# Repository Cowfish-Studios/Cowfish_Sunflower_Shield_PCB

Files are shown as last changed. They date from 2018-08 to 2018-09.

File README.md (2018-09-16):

Cowfish Studios Sunflower Shield
==============

Cowfish Studios Sunflower Shield

[*Cowfish Studios Sunflower Shield*](http://kck.st/2NdfVJ6)

The Sunflower Shield allows makers to add a 3.5" (QVGA) TFT LCD Display with capacitive touch to their Arduino projects.

Repository Contents
-------------------

* **/Hardware** - Eagle design files (.brd, .sch)

Documentation
--------------

* **[Hookup Guide](https://www.cowfishstudios.com/learn1/sunflower-shield-35-hmi-display-w-cap-touch-for-arduino)** - Basic hookup guide for the Sunflower Shield.

License Information
-------------------

This product is _**open source**_! 

Please review the LICENSE.md file for license information. 

If you have any questions or concerns on licensing, please contact support@cowfishstudios.com.

Distributed as-is; no warranty is given.

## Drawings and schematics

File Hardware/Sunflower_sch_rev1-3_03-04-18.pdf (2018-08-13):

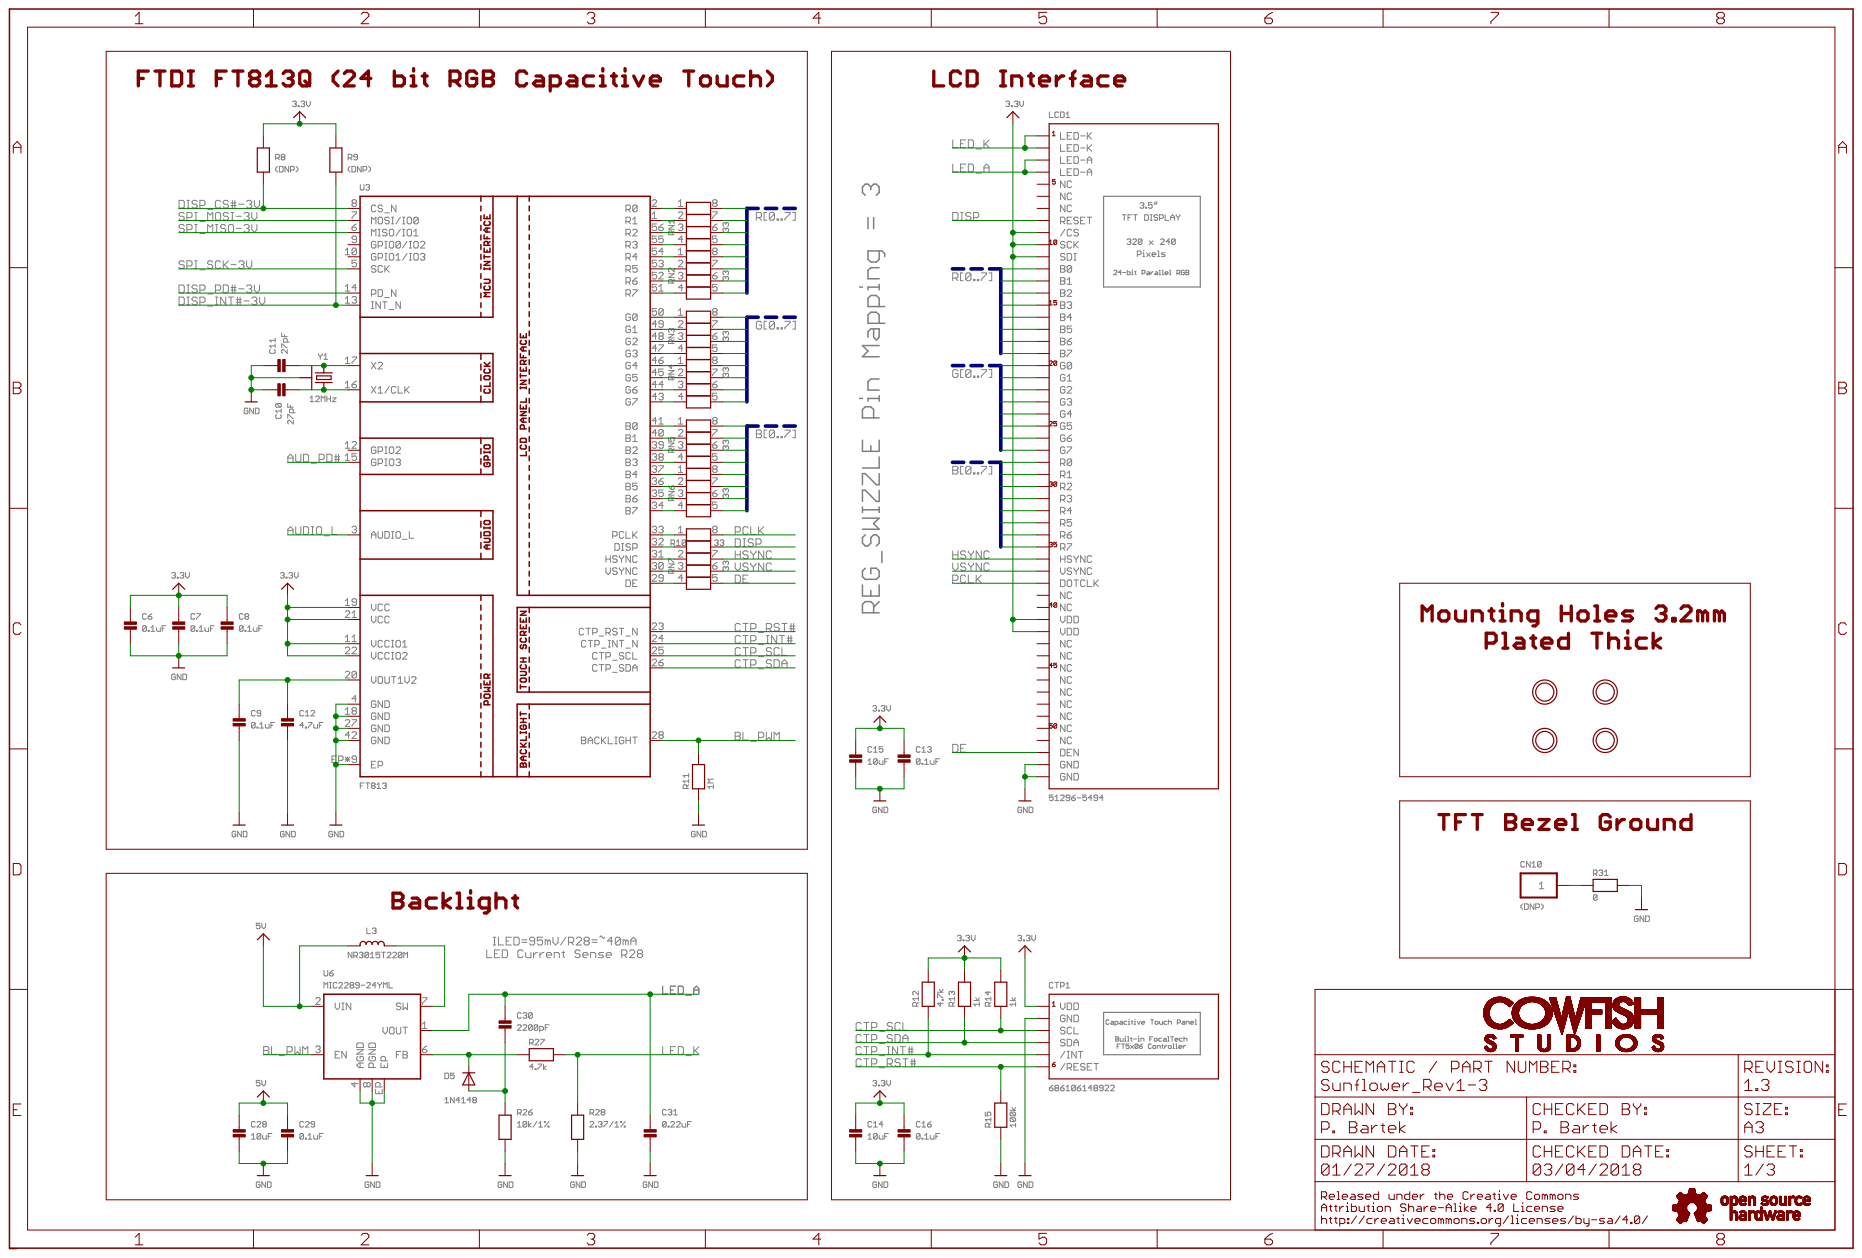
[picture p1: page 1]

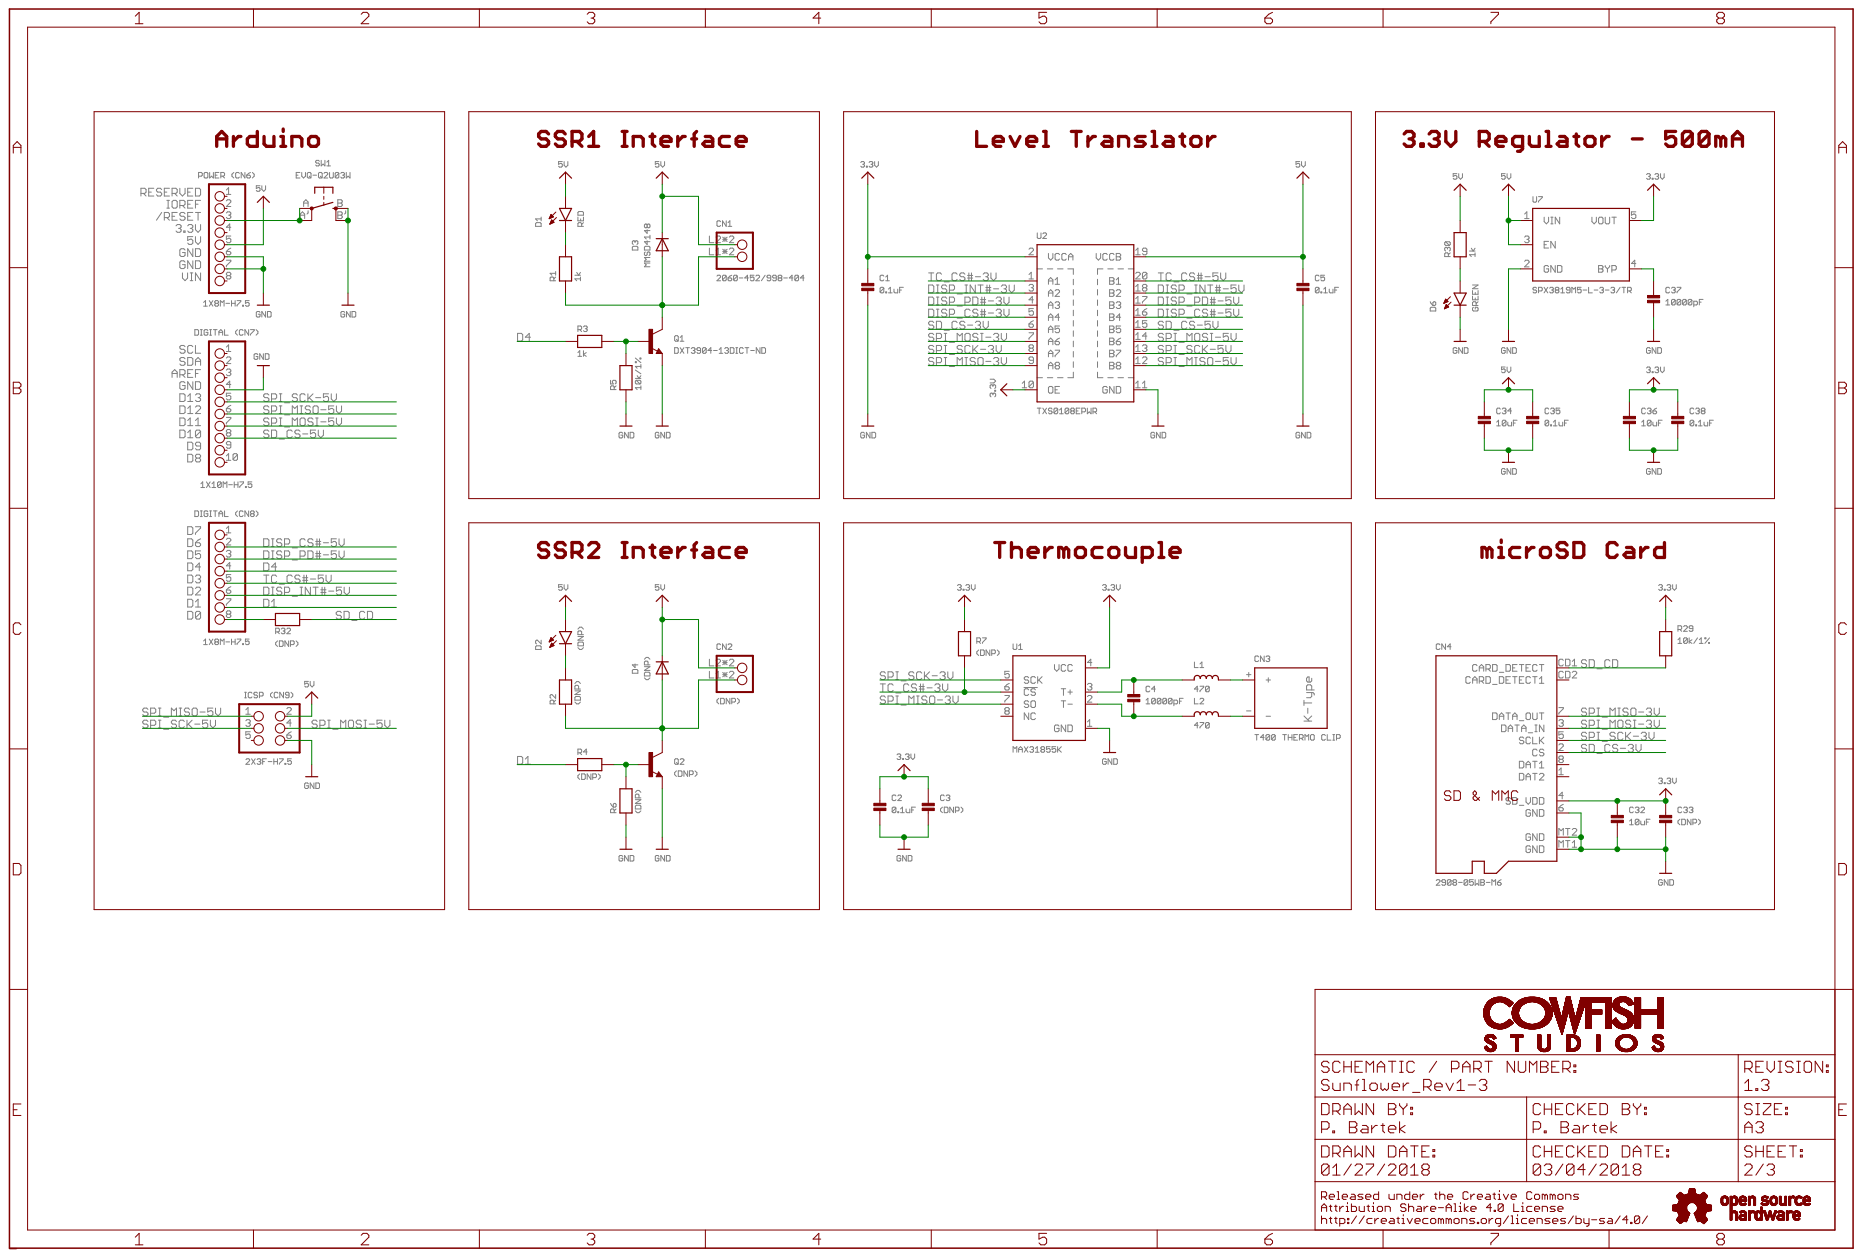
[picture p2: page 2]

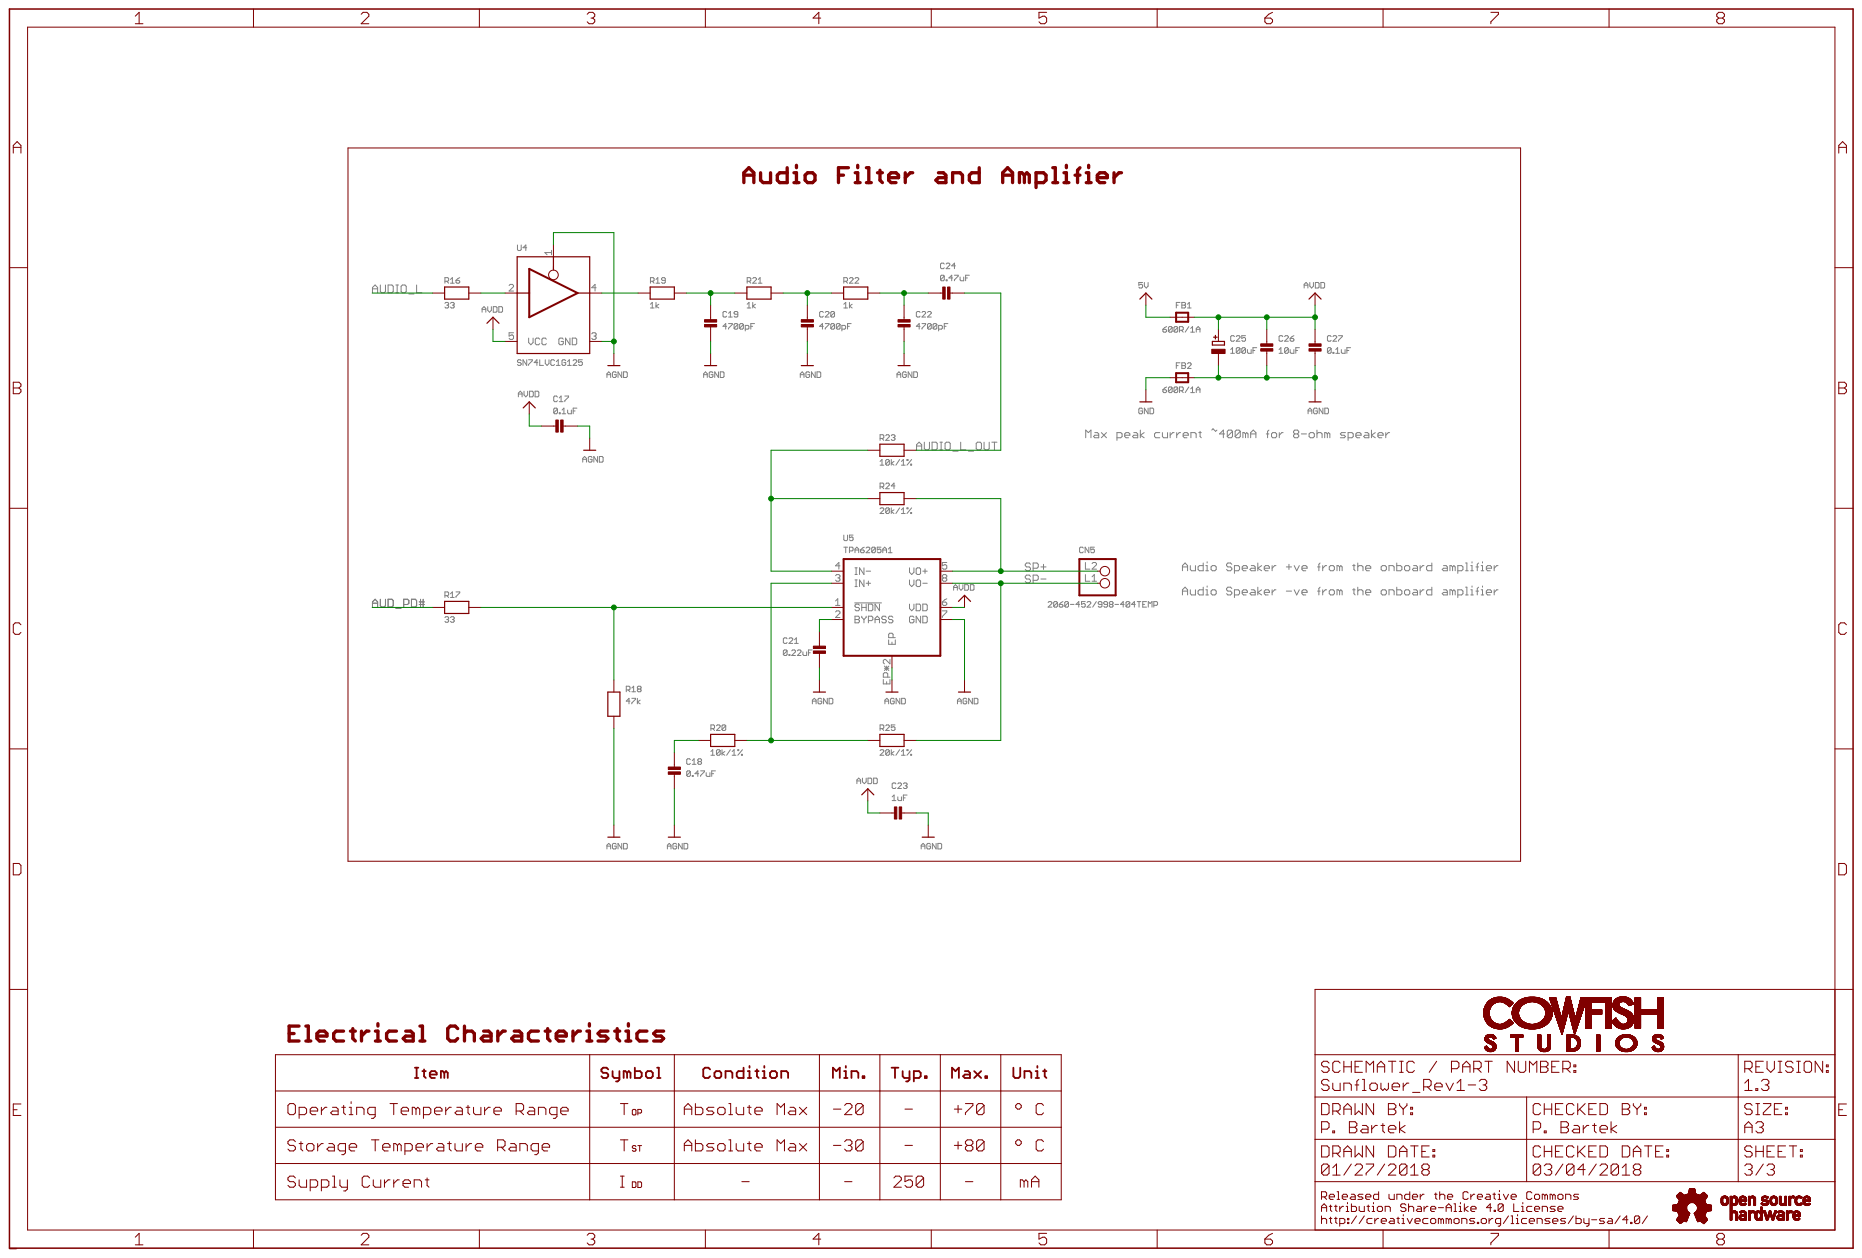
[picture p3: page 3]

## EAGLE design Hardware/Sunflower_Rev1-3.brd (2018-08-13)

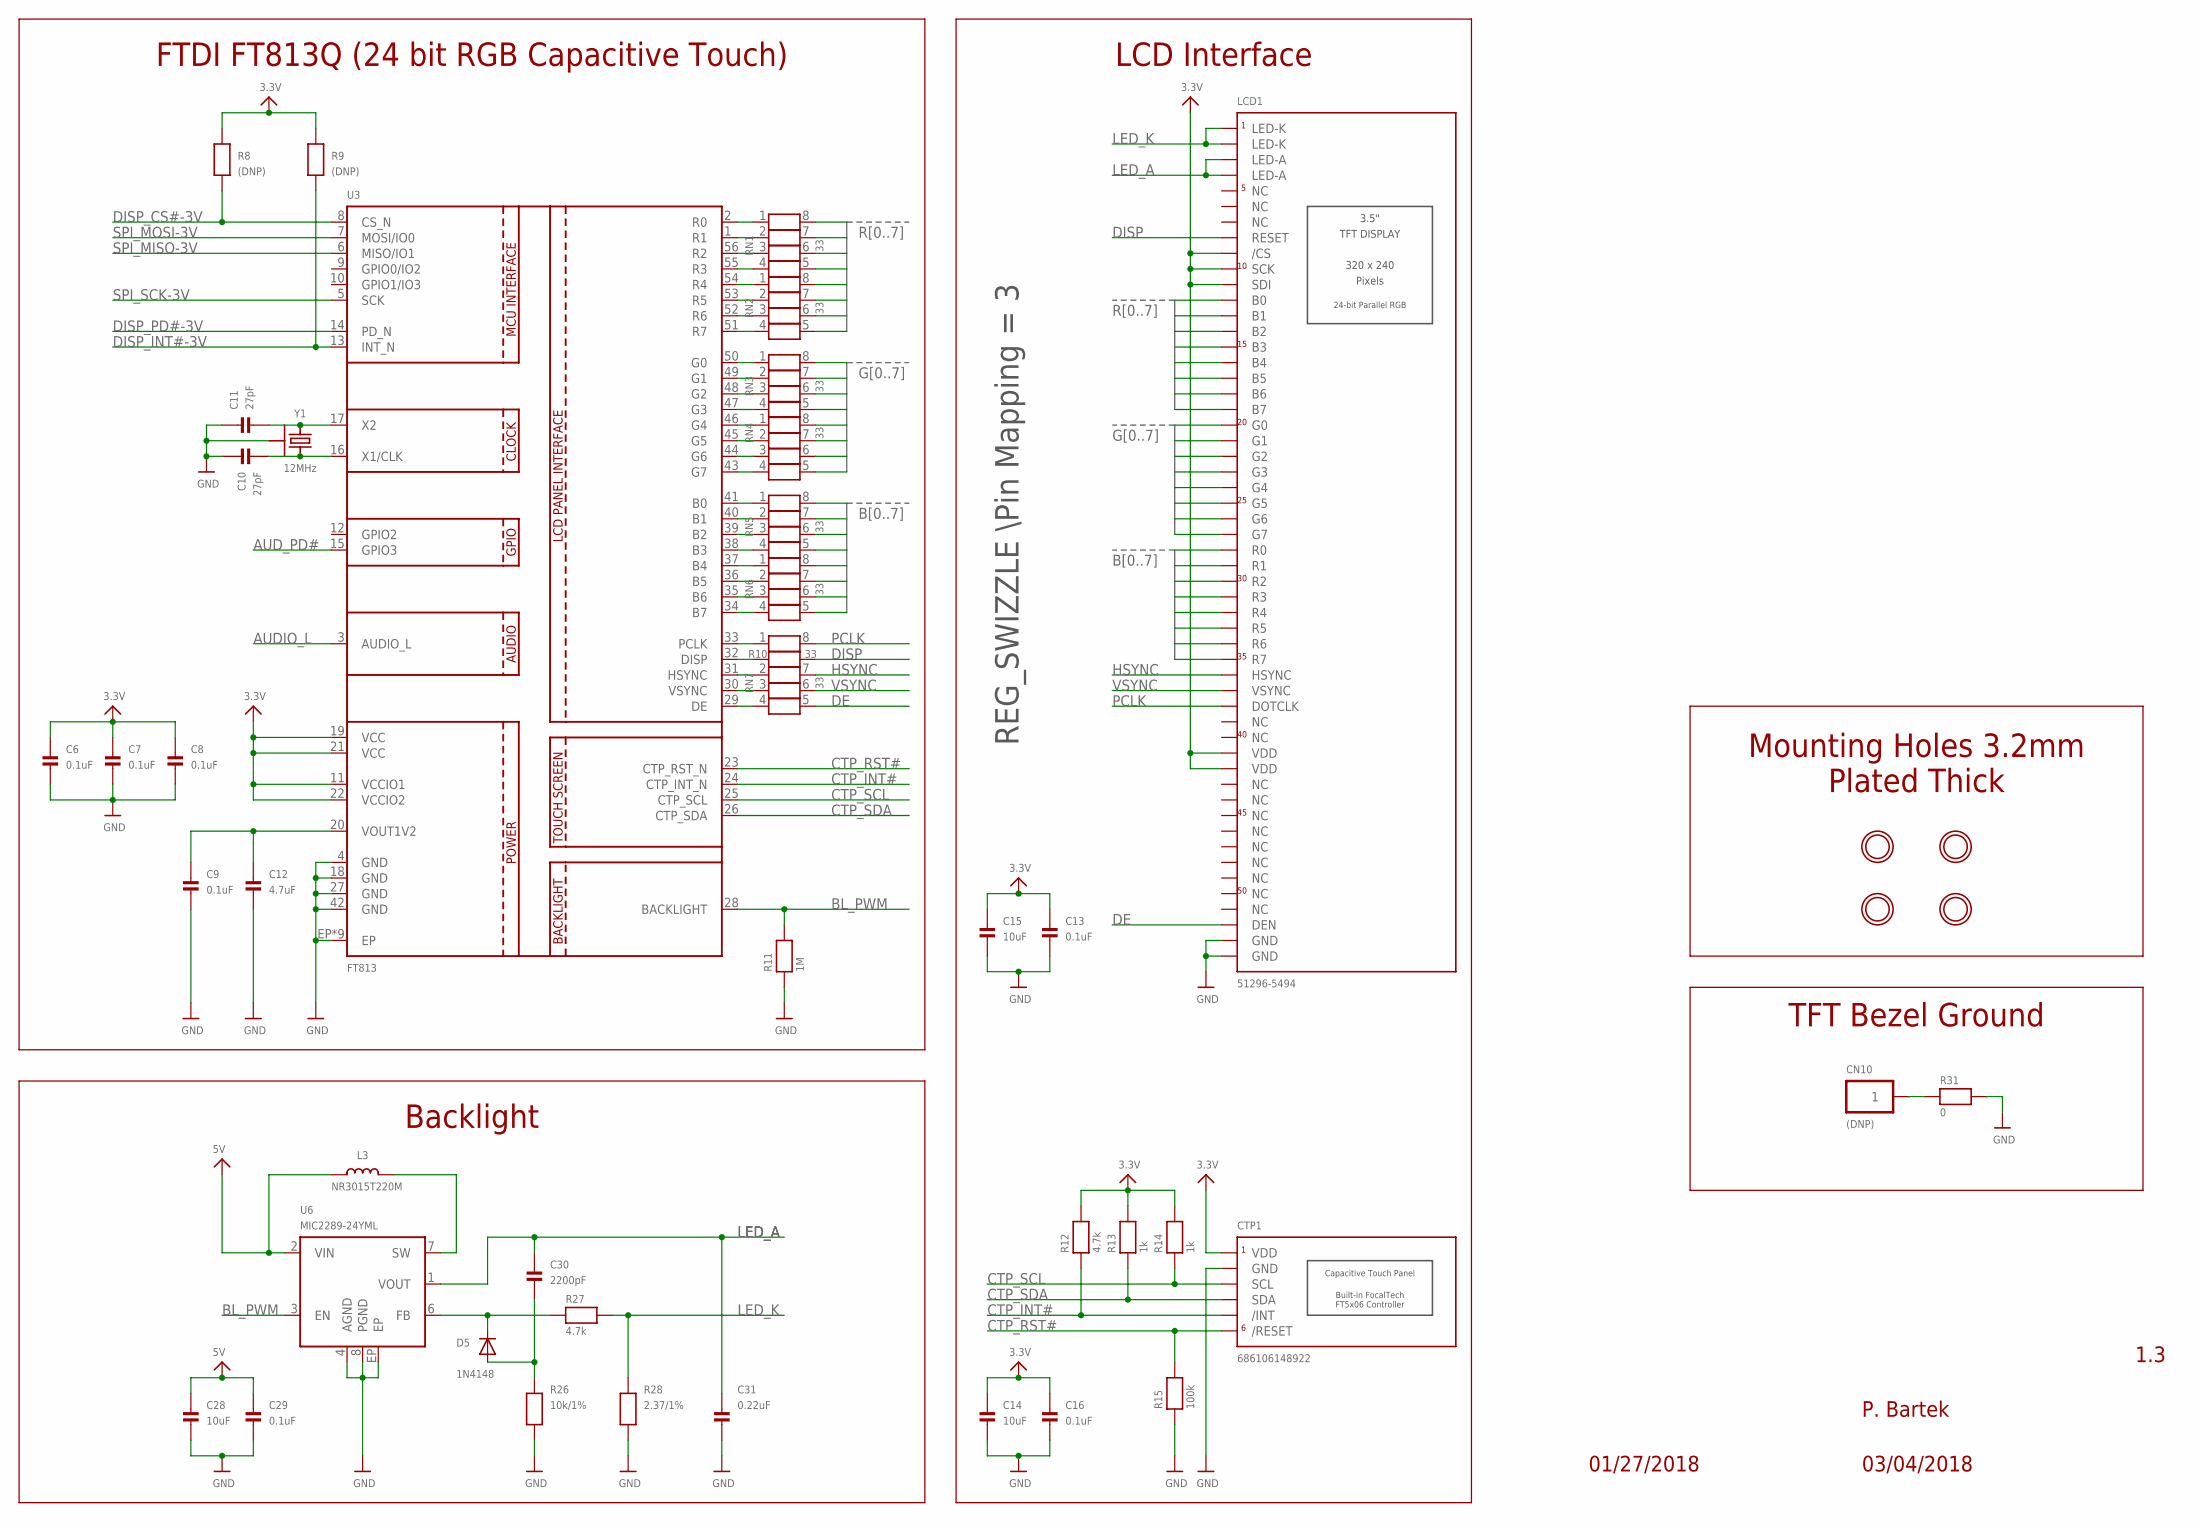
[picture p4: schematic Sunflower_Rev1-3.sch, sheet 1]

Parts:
C6, C7, C8, C9, C13, C16, C29: 0.1uF; 0603
C10, C11: 27pF; 0603
C12: 4.7uF; 0603
C14, C15, C28: 10uF; 0603
C30: 2200pF; 0603
C31: 0.22uF; 0603
CN10: (DNP); S7081-42R
CTP1: 686106148922; FPC_686106148922
D5: 1N4148; SOD-323
H1, H2, H3, H4: MOUNTINGHOLE3.2; MOUNTINGHOLE_3.2_PLATED
L3: NR3015T220M; INDUCTOR_3X3MM_TY_NR
LCD1: 51296-5494; FPC_51296_5494
R8, R9: (DNP); 0603
R10: 33; 0603
R11: 1M; 0603
R12, R27: 4.7k; 0603
R13, R14: 1k; 0603
R15: 100k; 0603
R26: 10k/1%; 0603
R28: 2.37/1%; 0805
R31: 0; 0603
RN1, RN2, RN3, RN4, RN5, RN6, RN7: 33; 741-8
U3: FT813; VQFN-56PIN
U6: MIC2289-24YML; MLF-8PIN
Y1: 12MHz; CRYSTAL_3.2X2.5

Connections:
3.3V: C6.1, C7.1, C8.1, C13.1, C14.1, C15.1, C16.1, CTP1.1 (VDD), LCD1.P$9 (/CS), LCD1.P$10 (SCK), LCD1.P$11 (SDI), LCD1.P$41 (VDD), LCD1.P$42 (VDD), R8.2, R9.2, R12.2, R13.2, R14.2, U3.11 (VCCIO1), U3.19 (VCC), U3.21 (VCC), U3.22 (VCCIO2); also elsewhere on the board
5V: C28.1, C29.1, L3.P$1 (1), U6.2 (VIN); also elsewhere on the board
AUDIO_L: U3.3 (AUDIO_L); also elsewhere on the board
AUD_PD#: U3.15 (GPIO3); also elsewhere on the board
B0: LCD1.P$28 (R0), RN5.8 (2)
B1: LCD1.P$29 (R1), RN5.7 (2)
B2: LCD1.P$30 (R2), RN5.6 (2)
B3: LCD1.P$31 (R3), RN5.5 (2)
B4: LCD1.P$32 (R4), RN6.8 (2)
B5: LCD1.P$33 (R5), RN6.7 (2)
B6: LCD1.P$34 (R6), RN6.6 (2)
B7: LCD1.P$35 (R7), RN6.5 (2)
BL_PWM: R11.2, U3.28 (BACKLIGHT), U6.3 (EN)
CTP_INT#: CTP1.5 (/INT), R12.1, U3.24 (CTP_INT_N)
CTP_RST#: CTP1.6 (/RESET), R15.2, U3.23 (CTP_RST_N)
CTP_SCL: CTP1.3 (SCL), R14.1, U3.25 (CTP_SCL)
CTP_SDA: CTP1.4 (SDA), R13.1, U3.26 (CTP_SDA)
DE: LCD1.P$52 (DEN), RN7.5 (2)
DISP: LCD1.P$8 (RESET), R10.2
DISP_CS#-3V: R8.1, U3.8 (CS_N); also elsewhere on the board
DISP_INT#-3V: R9.1, U3.13 (INT_N); also elsewhere on the board
DISP_PD#-3V: U3.14 (PD_N); also elsewhere on the board
G0: LCD1.P$20 (G0), RN3.8 (2)
G1: LCD1.P$21 (G1), RN3.7 (2)
G2: LCD1.P$22 (G2), RN3.6 (2)
G3: LCD1.P$23 (G3), RN3.5 (2)
G4: LCD1.P$24 (G4), RN4.8 (2)
G5: LCD1.P$25 (G5), RN4.7 (2)
G6: LCD1.P$26 (G6), RN4.6 (2)
G7: LCD1.P$27 (G7), RN4.5 (2)
GND: C6.2, C7.2, C8.2, C9.2, C10.2, C11.1, C12.2, C13.2, C14.2, C15.2, C16.2, C28.2, C29.2, C31.2, CTP1.2 (GND), CTP1.SUPPORT1 (GND), CTP1.SUPPORT2 (GND), LCD1.P$53 (GND), LCD1.P$54 (GND), LCD1.SUPPORT1 (GND), LCD1.SUPPORT2 (GND), R11.1, R15.1, R26.1, R28.1, R31.2, U3.4 (GND), U3.18 (GND), U3.27 (GND), U3.42 (GND), U3.EP, U3.TV@1 (EP), U3.TV@2 (EP), U3.TV@3 (EP), U3.TV@4 (EP), U3.TV@5 (EP), U3.TV@6 (EP), U3.TV@7 (EP), U3.TV@8 (EP), U6.4 (AGND), U6.8 (PGND), U6.EP, Y1.GND1 (3), Y1.GND2 (3); also elsewhere on the board
HSYNC: LCD1.P$36 (HSYNC), RN7.7 (2)
LED_A: C30.1, C31.1, LCD1.P$3 (LED-A), LCD1.P$4 (LED-A), U6.1 (VOUT)
LED_K: LCD1.P$1 (LED-K), LCD1.P$2 (LED-K), R27.2, R28.2
unnamed: RN1.1, U3.2 (R0)
unnamed: RN1.2 (1), U3.1 (R1)
unnamed: RN1.3 (1), U3.56 (R2)
unnamed: RN1.4 (1), U3.55 (R3)
unnamed: RN2.1, U3.54 (R4)
unnamed: RN2.2 (1), U3.53 (R5)
unnamed: RN2.3 (1), U3.52 (R6)
unnamed: RN2.4 (1), U3.51 (R7)
unnamed: RN3.1, U3.50 (G0)
unnamed: RN3.2 (1), U3.49 (G1)
unnamed: RN3.3 (1), U3.48 (G2)
unnamed: RN3.4 (1), U3.47 (G3)
unnamed: RN4.1, U3.46 (G4)
unnamed: RN4.2 (1), U3.45 (G5)
unnamed: RN4.3 (1), U3.44 (G6)
unnamed: RN4.4 (1), U3.43 (G7)
unnamed: RN5.1, U3.41 (B0)
unnamed: RN5.2 (1), U3.40 (B1)
unnamed: RN5.3 (1), U3.39 (B2)
unnamed: RN5.4 (1), U3.38 (B3)
unnamed: RN6.1, U3.37 (B4)
unnamed: RN6.2 (1), U3.36 (B5)
unnamed: RN6.3 (1), U3.35 (B6)
unnamed: RN6.4 (1), U3.34 (B7)
unnamed: RN7.1, U3.33 (PCLK)
unnamed: RN7.2 (1), U3.31 (HSYNC)
unnamed: RN7.3 (1), U3.30 (VSYNC)
unnamed: RN7.4 (1), U3.29 (DE)
unnamed: CN10.P$1, R31.1
unnamed: C11.2, U3.17 (X2), Y1.2
unnamed: C9.1, C12.1, U3.20 (VOUT1V2)
unnamed: C10.1, U3.16 (X1/CLK), Y1.1
unnamed: L3.P$2 (2), U6.7 (SW)
unnamed: D5.C, R27.1, U6.6 (FB)
unnamed: C30.2, D5.A, R26.2
unnamed: R10.1, U3.32 (DISP)
PCLK: LCD1.P$38 (DOTCLK), RN7.8 (2)
R0: LCD1.P$12 (B0), RN1.8 (2)
R1: LCD1.P$13 (B1), RN1.7 (2)
R2: LCD1.P$14 (B2), RN1.6 (2)
R3: LCD1.P$15 (B3), RN1.5 (2)
R4: LCD1.P$16 (B4), RN2.8 (2)
R5: LCD1.P$17 (B5), RN2.7 (2)
R6: LCD1.P$18 (B6), RN2.6 (2)
R7: LCD1.P$19 (B7), RN2.5 (2)
SPI_MISO-3V: U3.6 (MISO/IO1); also elsewhere on the board
SPI_MOSI-3V: U3.7 (MOSI/IO0); also elsewhere on the board
SPI_SCK-3V: U3.5 (SCK); also elsewhere on the board
VSYNC: LCD1.P$37 (VSYNC), RN7.6 (2)

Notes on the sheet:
REG_SWIZZLE \Pin Mapping = 3
LCD Interface
Backlight
FTDI FT813Q (24 bit RGB Capacitive Touch)
Mounting Holes 3.2mm Plated Thick
RN1
RN2
RN3
RN4
RN5
RN6
RN7
TFT Bezel Ground
P. Bartek
1.3
01/27/2018
03/04/2018

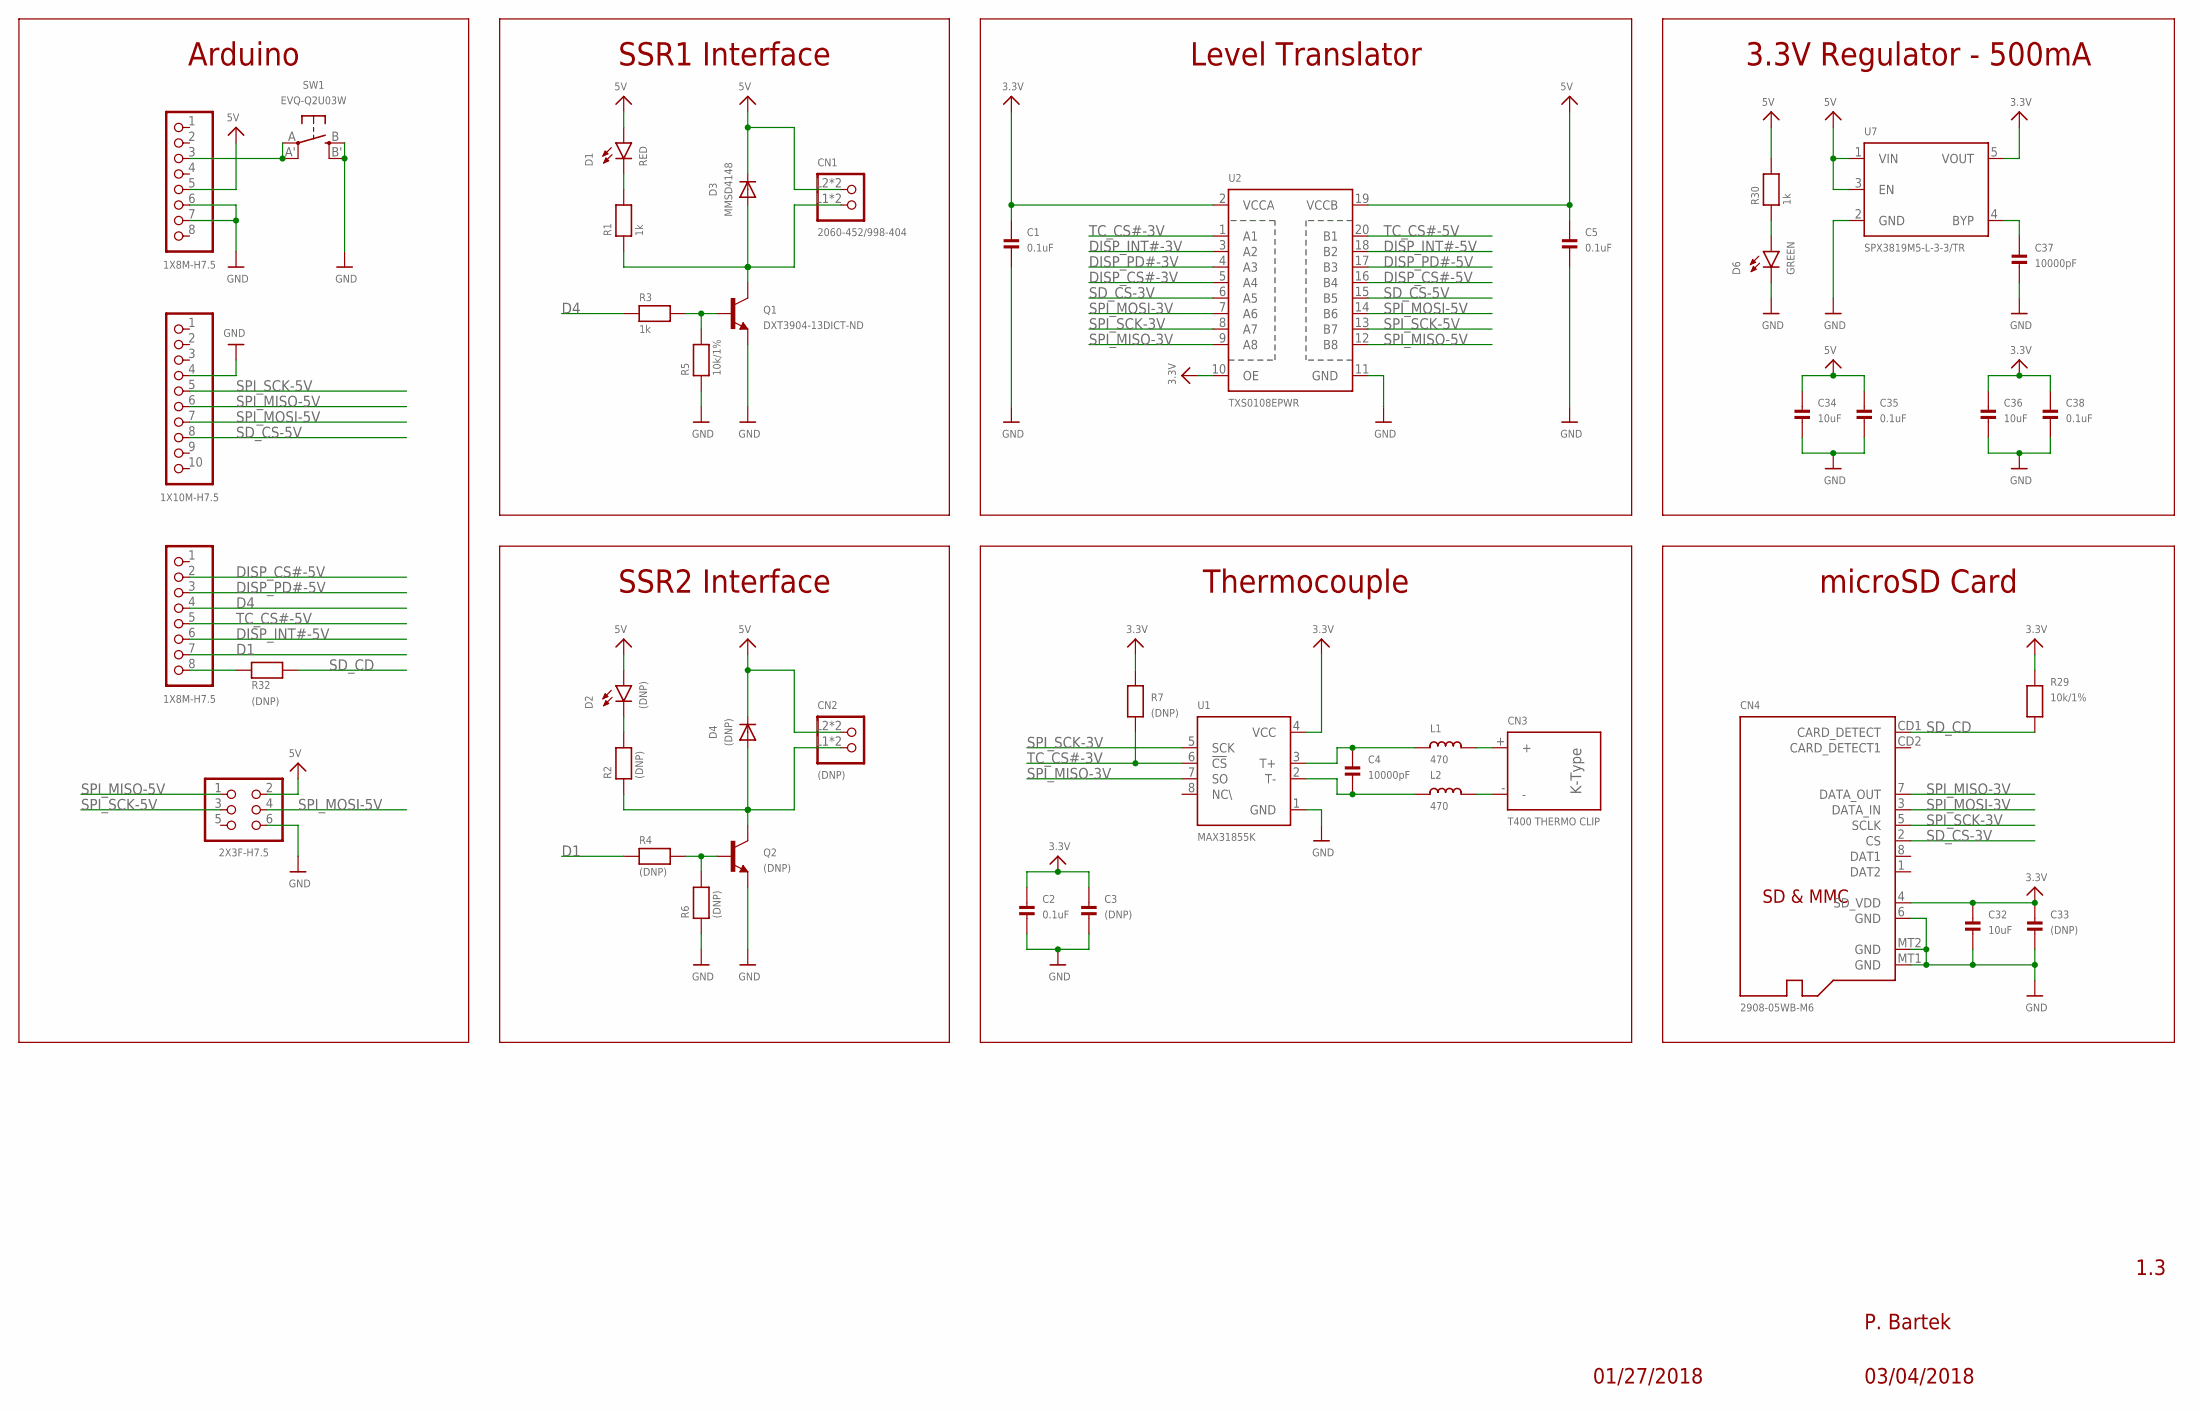
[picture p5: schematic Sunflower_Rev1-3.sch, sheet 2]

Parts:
C1, C2, C5, C35, C38: 0.1uF; 0603
C3, C33: (DNP); 0603
C4, C37: 10000pF; 0603
C32, C34, C36: 10uF; 0603
CN1: 2060-452/998-404; P-2060-452/998-404
CN2: (DNP); P-2060-452/998-404
CN3: T400 THERMO CLIP; THERMOCOUPLE_CLIP_INSIDE
CN4: 2908-05WB-M6; MICROSD
CN6, CN8: 1X8M-H7.5; 1X08_SMD_M_LEYCONN
CN7: 1X10M-H7.5; 1X10_SMD_M_LEYCONN
CN9: 2X3F-H7.5; 2X3_SMD_F_LEYCONN
D1: RED; LED-0603
D2: (DNP); LED-0603
D3: MMSD4148; SOD-123
D4: (DNP); SOD-123
D6: GREEN; LED-0603
L1, L2: 470; 0603
Q1: DXT3904-13DICT-ND; SOT-89-3
Q2: (DNP); SOT-89-3
R1, R3, R30: 1k; 0603
R2, R4, R6, R7, R32: (DNP); 0603
R5, R29: 10k/1%; 0603
SW1: EVQ-Q2U03W; EVQ-Q2
U1: MAX31855K; SOIC8
U2: TXS0108EPWR; TSSOP-20PIN
U7: SPX3819M5-L-3-3/TR; SOT23-5PIN

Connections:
3.3V: C1.1, C2.1, C3.1, C32.1, C33.1, C36.1, C38.1, CN4.4 (SD_VDD), R7.2, R29.2, U1.4 (VCC), U2.2 (VCCA), U2.10 (OE), U7.5 (VOUT); also elsewhere on the board
5V: C5.1, C34.1, C35.1, CN1.L2 (P1.1), CN1.L2.2 (P1.1), CN2.L2 (P1.1), CN2.L2.2 (P1.1), CN6.5, CN9.2, D1.A, D2.A, D3.C, D4.C, R30.2, U2.19 (VCCB), U7.1 (VIN), U7.3 (EN); also elsewhere on the board
D1: CN8.7, R4.1
D4: CN8.4, R3.1
DISP_CS#-3V: U2.5 (A4); also elsewhere on the board
DISP_CS#-5V: CN8.2, U2.16 (B4)
DISP_INT#-3V: U2.3 (A2); also elsewhere on the board
DISP_INT#-5V: CN8.6, U2.18 (B2)
DISP_PD#-3V: U2.4 (A3); also elsewhere on the board
DISP_PD#-5V: CN8.3, U2.17 (B3)
GND: C1.2, C2.2, C3.2, C5.2, C32.2, C33.2, C34.2, C35.2, C36.2, C37.2, C38.2, CN4.6 (GND), CN4.MT1 (GND), CN4.MT2 (GND), CN6.6, CN6.7, CN7.4, CN9.6, D6.C, Q1.E, Q2.E, R5.1, R6.1, SW1.B (S), SW1.B' (S1), U1.1 (GND), U2.11 (GND), U7.2 (GND); also elsewhere on the board
unnamed: D6.A, R30.1
unnamed: C4.1, L1.1, U1.3 (T+)
unnamed: C4.2, L2.1, U1.2 (T-)
unnamed: CN3.+, L1.2
unnamed: CN3.-, L2.2
unnamed: C37.1, U7.4 (BYP)
unnamed: Q1.B, R3.2, R5.2
unnamed: Q2.B, R4.2, R6.2
unnamed: CN1.L1 (P2.1), CN1.L1.2 (P2.1), D3.A, Q1.C, Q1.C@1 (C), R1.1
unnamed: D1.C, R1.2
unnamed: CN8.8, R32.1
unnamed: D2.C, R2.2
unnamed: CN2.L1 (P2.1), CN2.L1.2 (P2.1), D4.A, Q2.C, Q2.C@1 (C), R2.1
unnamed: CN6.3, SW1.A, SW1.A' (P1)
SD_CD: CN4.CD1 (CARD_DETECT), R29.1, R32.2
SD_CS-3V: CN4.2 (CS), U2.6 (A5)
SD_CS-5V: CN7.8, U2.15 (B5)
SPI_MISO-3V: CN4.7 (DATA_OUT), U1.7 (SO), U2.9 (A8); also elsewhere on the board
SPI_MISO-5V: CN7.6, CN9.1, U2.12 (B8)
SPI_MOSI-3V: CN4.3 (DATA_IN), U2.7 (A6); also elsewhere on the board
SPI_MOSI-5V: CN7.7, CN9.4, U2.14 (B6)
SPI_SCK-3V: CN4.5 (SCLK), U1.5 (SCK), U2.8 (A7); also elsewhere on the board
SPI_SCK-5V: CN7.5, CN9.3, U2.13 (B7)
TC_CS#-3V: R7.1, U1.6 (!CS), U2.1 (A1)
TC_CS#-5V: CN8.5, U2.20 (B1)

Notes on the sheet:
3.3V Regulator - 500mA
Thermocouple
Level Translator
microSD Card
Arduino
SSR1 Interface
SSR2 Interface
P. Bartek
1.3
01/27/2018
03/04/2018

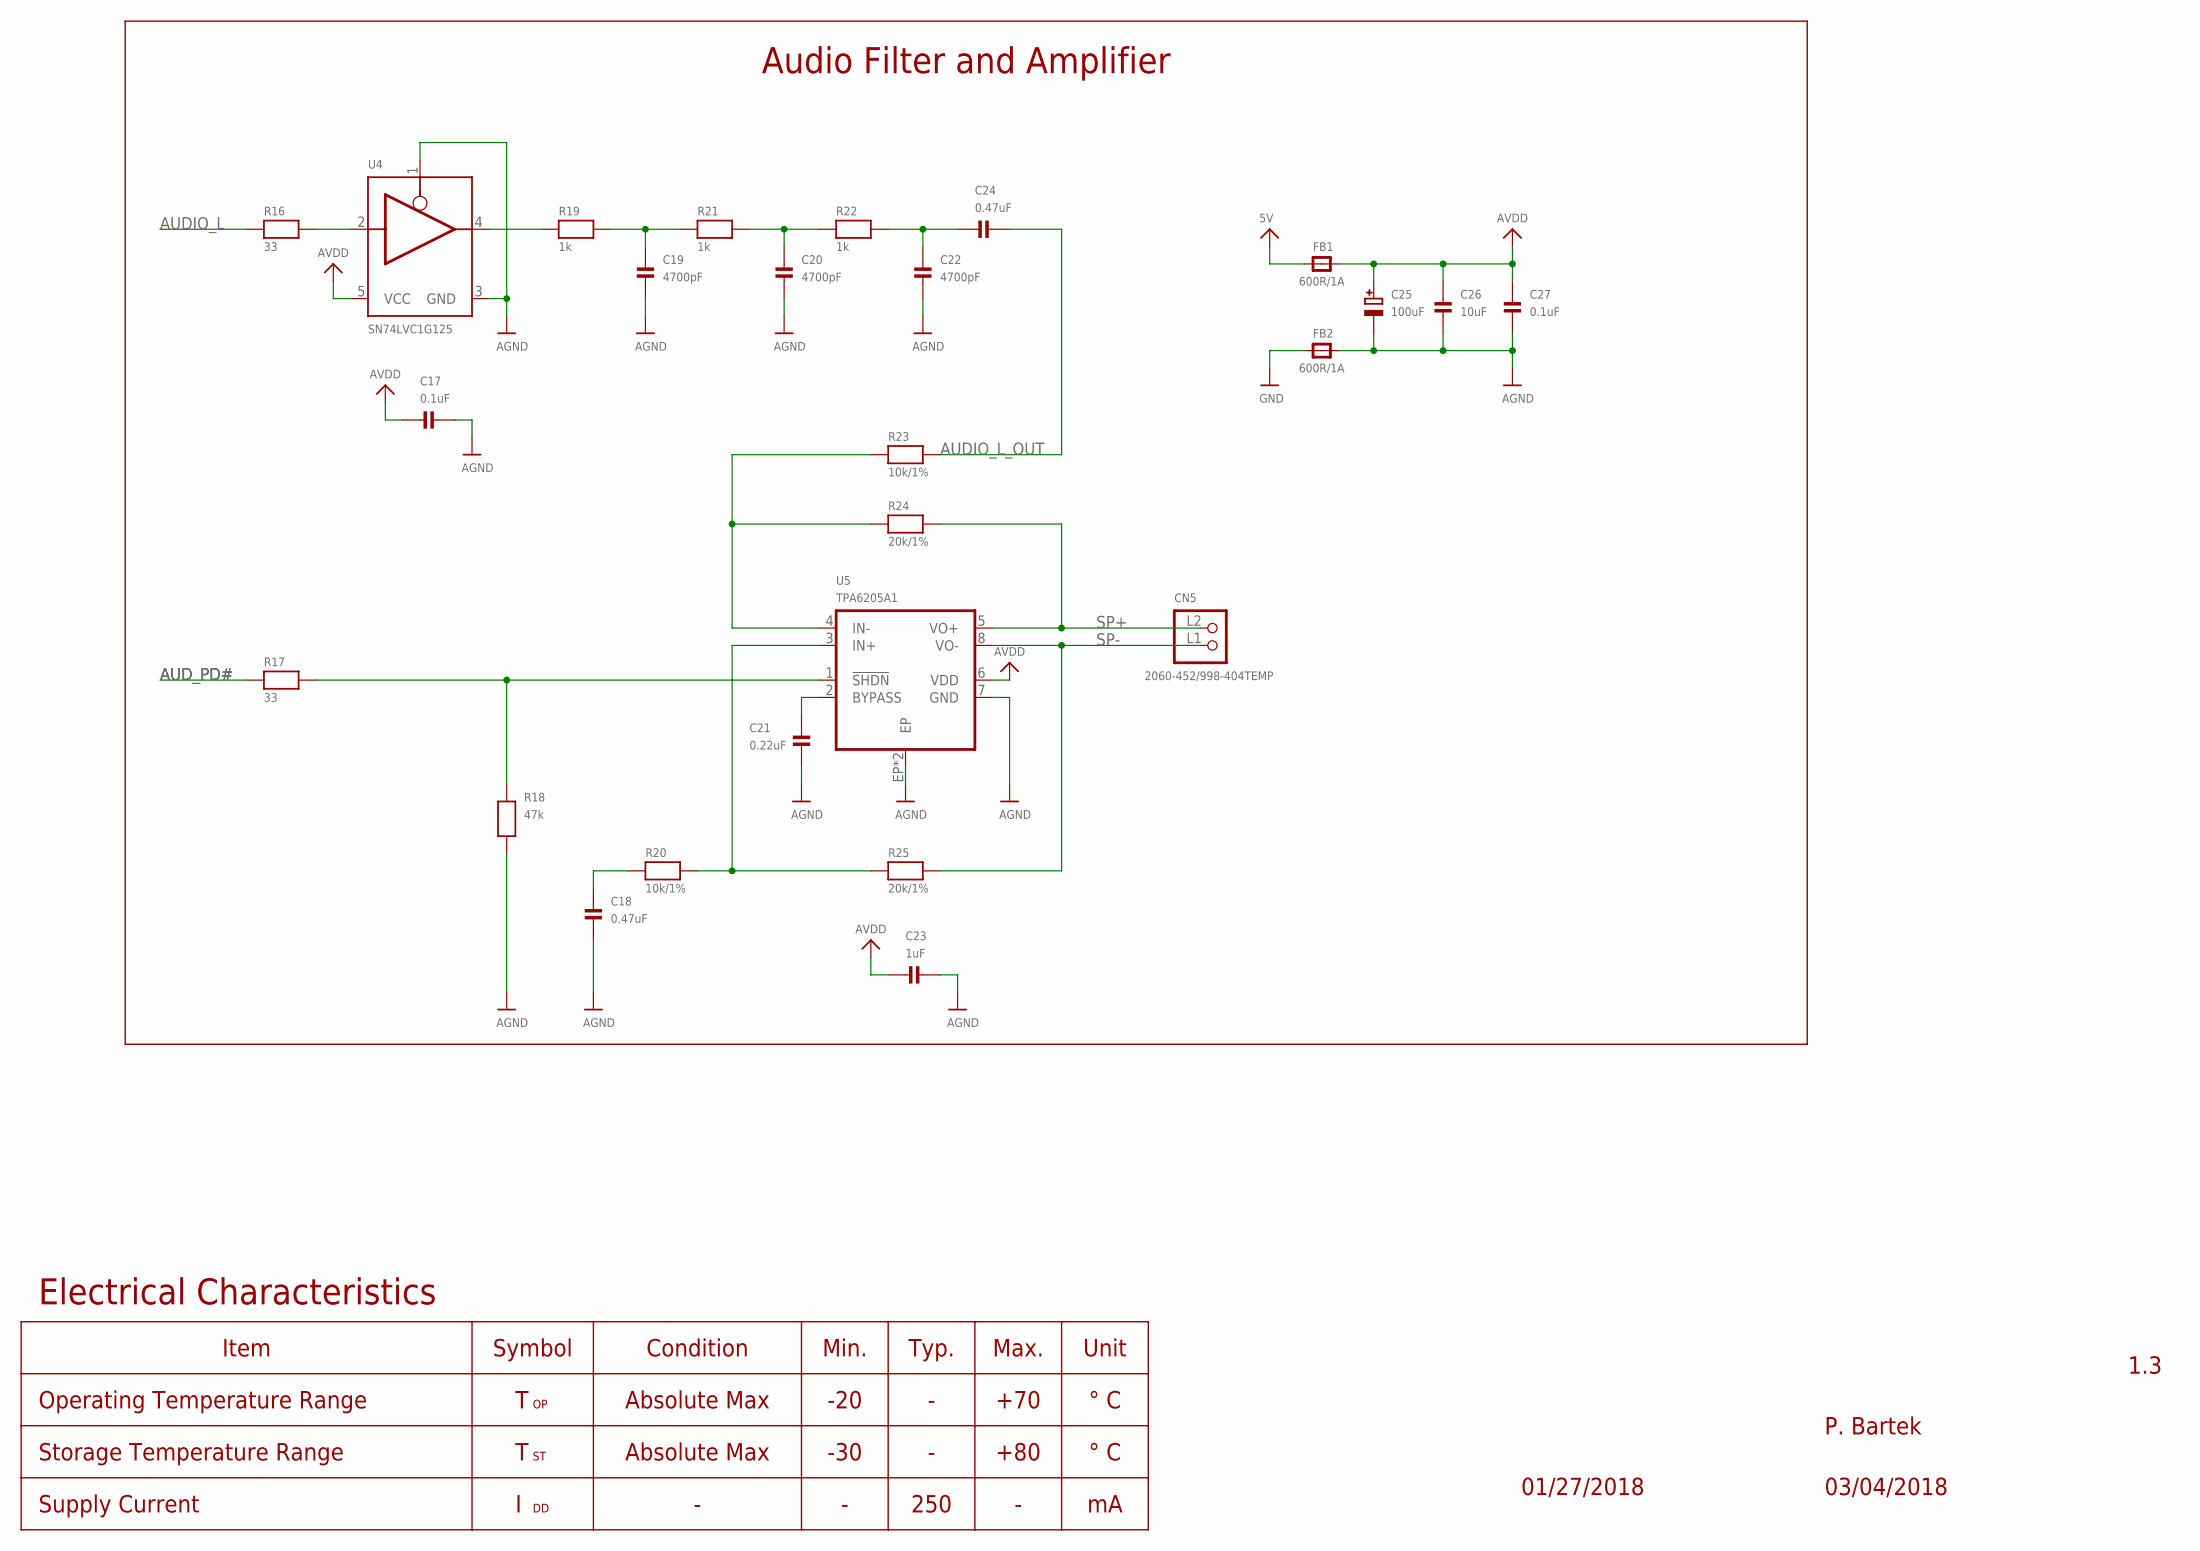
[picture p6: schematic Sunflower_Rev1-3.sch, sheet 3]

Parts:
C17, C27: 0.1uF; 0603
C18, C24: 0.47uF; 0603
C19, C20, C22: 4700pF; 0603
C21: 0.22uF; 0805
C23: 1uF; 0603
C25: 100uF; EIA3216-18/A-R
C26: 10uF; 0603
CN5: 2060-452/998-404TEMP; P-2060-452/998-404
FB1, FB2: 600R/1A; 0805
R16, R17: 33; 0603
R18: 47k; 0603
R19, R21, R22: 1k; 0603
R20, R23: 10k/1%; 0603
R24, R25: 20k/1%; 0603
U4: SN74LVC1G125; SOT23-5PIN
U5: TPA6205A1; MSOP-8PIN

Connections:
5V: FB1.1; also elsewhere on the board
AGND: C17.2, C18.2, C19.2, C20.2, C21.2, C22.2, C23.2, C25.-, C26.2, C27.2, FB2.2, R18.1, U4.1 (OE), U4.3 (GND), U5.7 (GND), U5.EP, U5.TV (EP)
AUDIO_L: R16.1; also elsewhere on the board
AUDIO_L_OUT: C24.2, R23.2
AUD_PD#: R17.1; also elsewhere on the board
AVDD: C17.1, C23.1, C25.+, C26.1, C27.1, FB1.2, U4.5 (VCC), U5.6 (VDD)
GND: FB2.1; also elsewhere on the board
unnamed: R16.2, U4.2 (I)
unnamed: R17.2, R18.2, U5.1 (!SHDN)
unnamed: R19.1, U4.4 (O)
unnamed: C19.1, R19.2, R21.1
unnamed: C20.1, R21.2, R22.1
unnamed: C21.1, U5.2 (BYPASS)
unnamed: C22.1, C24.1, R22.2
unnamed: R20.2, R25.1, U5.3 (IN+)
unnamed: C18.1, R20.1
unnamed: R23.1, R24.1, U5.4 (IN-)
SP+: CN5.L2 (P1.1), R24.2, U5.5 (VO+)
SP-: CN5.L1 (P2.1), R25.2, U5.8 (VO-)

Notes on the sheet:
Audio Filter and Amplifier
Electrical Characteristics
Operating Temperature Range
Item
Storage Temperature Range
Supply Current
Symbol
Condition
Absolute Max
Min.
Typ.
Max.
Unit
-20
-30
+70
+80
° C
250
P. Bartek
1.3
01/27/2018
03/04/2018

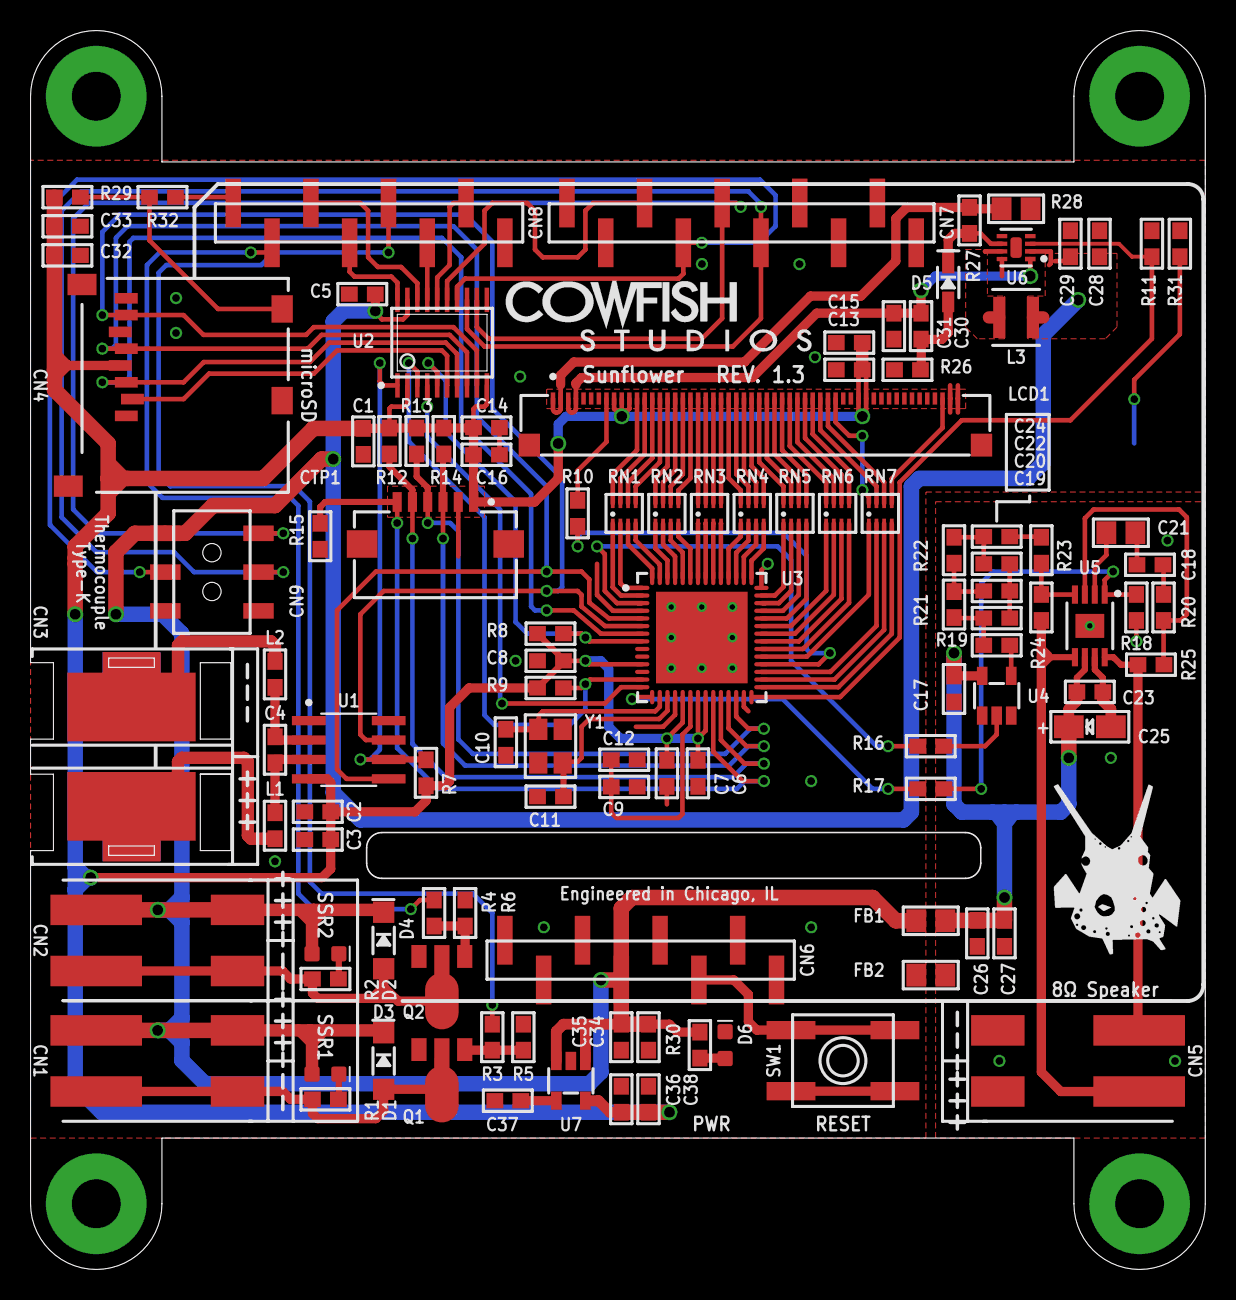
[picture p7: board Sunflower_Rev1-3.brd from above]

Board: 2 copper layers, 76.9 x 81.1 mm, 115 parts (1 on the bottom side), 125 nets.

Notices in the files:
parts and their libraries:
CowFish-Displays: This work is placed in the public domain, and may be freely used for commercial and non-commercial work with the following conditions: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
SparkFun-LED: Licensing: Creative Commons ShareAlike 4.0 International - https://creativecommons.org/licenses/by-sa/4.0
